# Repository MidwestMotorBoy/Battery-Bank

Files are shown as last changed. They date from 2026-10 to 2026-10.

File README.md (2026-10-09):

# Monolith battery bank

An ultralight 100 W USB-C battery bank for backpacking: four EVE INR21700-58E cells (4S1P, about 82 Wh) in a printed tube.

**Status: early draft. Nothing here has been built, test-fitted or bench-tested.**

## Contents

- `BatteryBank.kicad_*` - KiCad 10 project for the top board. The schematic is a first draft with connections made by net labels; the PCB has the outline and mechanical reference marks only.
- `Monolith.kicad_sym`, `sym-lib-table` - project symbol library.
- `docs/` - net list and early parts lists.
- `mechanical/` - STL models for the shell, cap and test-print parts, the bottom board outline (DXF), and the Python scripts that generate them.
- `tools/` - Python scripts that generate the schematic.

## Main parts

TPS25751D (USB-C PD), BQ25756 (charger and buck-boost), BQ77915 (cell protection), TPS25810 (5 V port), TPS62933 and TPS70933 (rails), STM32WB1MMC (Bluetooth).

## Known open items

Several parts are placeholders (FETs, inductors, EEPROM), no footprints are assigned, the port 1 ESD protection is not drawn, and a number of pin connections are marked for checking against the datasheets.

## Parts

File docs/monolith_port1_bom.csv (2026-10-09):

ref | part | value_or_role | package | status | JLC_part_number
U1 | TPS25751D | USB-C PD controller | WQFN-38 4x6mm | confirmed from TI datasheet
U2 | BQ25756 | Buck-boost charge controller | VQFN-36 5x6mm | confirmed from TI datasheet
Q1 | N-FET 40V <=6mOhm logic-level | Buck high side | 3.3x3.3mm | to be selected
Q2 | N-FET 40V <=6mOhm logic-level | Buck low side | 3.3x3.3mm | to be selected
Q3 | N-FET 40V <=6mOhm logic-level | Boost low side | 3.3x3.3mm | to be selected
Q4 | N-FET 40V <=6mOhm logic-level | Boost high side | 3.3x3.3mm | to be selected
L1 | Inductor | 4.7uH, Isat>=12A, <=5mm tall | about 10x10mm | to be selected
R1 | Sense resistor | 5mOhm 1% 1W | 2512 or 1206 wide | assumed, verify
R2 | Sense resistor | 5mOhm 1% 1W | 2512 or 1206 wide | confirmed from TI datasheet
C1 | Bootstrap cap | 100nF 25V | 0402 | assumed, verify
C2 | Bootstrap cap | 100nF 25V | 0402 | assumed, verify
C3 | REGN cap | 4.7uF 10V | 0603 | confirmed from TI datasheet
C4 | DRV_SUP cap | 4.7uF 10V | 0603 | confirmed from TI datasheet
C5 | VAC cap | 1uF 35V | 0603 | confirmed from TI datasheet
R3 | VAC feed | 10 Ohm | 0402 | assumed, verify
C6-C9 | Input bulk (port side) | 4x 22uF 35V X7R, plus C10 | 1210 | assumed, verify
C10 | Input bulk polymer | 68uF 25V, <=5mm tall | D case | assumed, verify
C11-C14 | Output bulk (battery side) | 4x 22uF 25V X7R, plus C15 | 1210 | assumed, verify
C15 | Battery bulk polymer | 68uF 25V, <=5mm tall | D case | assumed, verify
R4 | FB top | 243k 0.1% | 0402 | assumed, verify
R5 | FB bottom | 24.9k 0.1% | 0402 | assumed, verify
R6 | ICHG set | 16.9k 1% (2.96A) | 0402 | confirmed from TI datasheet
R7 | ILIM set | 4.02k 1% (about 5A with 5mOhm R1) | 0402 | assumed, verify
R8 | FSW set | 66.5k 1% (400kHz) | 0402 | confirmed from TI datasheet
R9 | TS upper | 5.23k 1% | 0402 | confirmed from TI datasheet
R10 | TS lower | 30.1k 1% | 0402 | confirmed from TI datasheet
RT1 | NTC on cell | 10k 103AT, on leads | wired | confirmed from TI datasheet
R11 | ACUV/ACOV divider top | value from datasheet section 6.3 | 0402 | to be selected
R12 | ACUV/ACOV divider mid | value from datasheet section 6.3 | 0402 | to be selected
R13 | ACUV/ACOV divider bottom | value from datasheet section 6.3 | 0402 | to be selected
R14 | CE pull-down | 10k | 0402 | assumed, verify
R15 | INT pull-up | 10k | 0402 | confirmed from TI datasheet
R16 | I2Cc SDA pull-up | 3.3k | 0402 | confirmed from TI datasheet
R17 | I2Cc SCL pull-up | 3.3k | 0402 | confirmed from TI datasheet
R18 | I2Ct SDA pull-up | 4.7k | 0402 | confirmed from TI datasheet
R19 | I2Ct SCL pull-up | 4.7k | 0402 | confirmed from TI datasheet
R20 | Host IRQ pull-up | 10k | 0402 | assumed, verify
R21-R23 | STAT1/STAT2/PG pull-ups | 3x 100k | 0402 | assumed, verify
C16 | LDO_3V3 cap | 10uF 6.3V | 0603 | confirmed from TI datasheet
C17 | LDO_1V5 cap | 10uF 6.3V | 0603 | confirmed from TI datasheet
C18 | VIN_3V3 cap | 10uF 6.3V | 0603 | confirmed from TI datasheet
C19 | VBUS cap | 4.7uF 35V | 0805 | confirmed from TI datasheet
C20 | PP5V cap | 22uF 10V | 0805 | confirmed from TI datasheet
C21 | CC1 cap | 330pF | 0402 | confirmed from TI datasheet
C22 | CC2 cap | 330pF | 0402 | confirmed from TI datasheet
R24,R25 | ADCIN1 strap divider | level chosen in TI GUI | 0402 | to be selected
R26,R27 | ADCIN2 strap divider | level chosen in TI GUI | 0402 | to be selected
U3 | I2C EEPROM | size and address per TPS25751 datasheet | SOT-23-5 or UDFN | to be selected
D1 | VBUS TVS | TVS2200 or equivalent | SON | confirmed from TI datasheet
D2 | CC/D+/D- ESD array | 4-channel, 24V-tolerant on CC | SOT/DFN | to be selected
J1 | Amphenol 12402082E512A | Port 1 USB-C | vertical SMT | assumed, verify
(block) | BQ77915 + 2 FETs + 5mOhm sense + 15A fuse | Protector: between cell stack and VBAT_SYS |  | pinout not yet pulled
(block) | TPS709 LDO | 3.3V rail: VBAT_SYS -> 3V3 |  | pinout not yet pulled
(block) | TPS62933 buck, J2, 4.7k CC pull-ups | 5V rail and port 2: VBAT_SYS -> 5V, 5V -> VBUS2 through a load switch |  | pinout not yet pulled
(block) | Ebyte E104-BT5005A | Bluetooth: HOST_SDA, HOST_SCL, HOST_IRQ, CHG_STAT1/2, CHG_PG, LEDs, SWD pads |  | pinout not yet pulled

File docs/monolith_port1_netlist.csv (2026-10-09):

ref | part | value_or_role | pin | pin_name | net | status
U1 | TPS25751D | USB-C PD controller | 1 | LDO_3V3 | PD_3V3 | confirmed from TI datasheet
U1 | TPS25751D | USB-C PD controller | 2 | ADCIN1 | ADCIN1 | confirmed from TI datasheet
U1 | TPS25751D | USB-C PD controller | 3 | ADCIN2 | ADCIN2 | confirmed from TI datasheet
U1 | TPS25751D | USB-C PD controller | 4 | LDO_1V5 | PD_1V5 | confirmed from TI datasheet
U1 | TPS25751D | USB-C PD controller | 5 | GPIO0 | GND | confirmed from TI datasheet
U1 | TPS25751D | USB-C PD controller | 6 | GPIO1 | GND | confirmed from TI datasheet
U1 | TPS25751D | USB-C PD controller | 7 | GPIO2 | GND | confirmed from TI datasheet
U1 | TPS25751D | USB-C PD controller | 8 | I2Ct_SDA | HOST_SDA | confirmed from TI datasheet
U1 | TPS25751D | USB-C PD controller | 9 | I2Ct_SCL | HOST_SCL | confirmed from TI datasheet
U1 | TPS25751D | USB-C PD controller | 10 | I2Ct_IRQ | HOST_IRQ | confirmed from TI datasheet
U1 | TPS25751D | USB-C PD controller | 11 | GND | GND | confirmed from TI datasheet
U1 | TPS25751D | USB-C PD controller | 12 | GND | GND | confirmed from TI datasheet
U1 | TPS25751D | USB-C PD controller | 13 | GPIO11 | GND | confirmed from TI datasheet
U1 | TPS25751D | USB-C PD controller | 14 | GND | GND | confirmed from TI datasheet
U1 | TPS25751D | USB-C PD controller | 15 | DRAIN | PD_DRAIN | confirmed from TI datasheet
U1 | TPS25751D | USB-C PD controller | 16 | I2Cc_SDA | CHG_SDA | confirmed from TI datasheet
U1 | TPS25751D | USB-C PD controller | 17 | I2Cc_SCL | CHG_SCL | confirmed from TI datasheet
U1 | TPS25751D | USB-C PD controller | 18 | I2Cc_IRQ | CHG_INT | confirmed from TI datasheet
U1 | TPS25751D | USB-C PD controller | 19 | GPIO3 | GND | confirmed from TI datasheet
U1 | TPS25751D | USB-C PD controller | 20 | PPHV | PPHV | confirmed from TI datasheet
U1 | TPS25751D | USB-C PD controller | 21 | PPHV | PPHV | confirmed from TI datasheet
U1 | TPS25751D | USB-C PD controller | 22 | PPHV | PPHV | confirmed from TI datasheet
U1 | TPS25751D | USB-C PD controller | 23 | VBUS_IN | VBUS1 | confirmed from TI datasheet
U1 | TPS25751D | USB-C PD controller | 24 | VBUS_IN | VBUS1 | confirmed from TI datasheet
U1 | TPS25751D | USB-C PD controller | 25 | VBUS_IN | VBUS1 | confirmed from TI datasheet
U1 | TPS25751D | USB-C PD controller | 26 | GPIO4/USB_P | P1_DP | confirmed from TI datasheet
U1 | TPS25751D | USB-C PD controller | 27 | GPIO5/USB_N | P1_DN | confirmed from TI datasheet
U1 | TPS25751D | USB-C PD controller | 28 | CC1 | P1_CC1 | confirmed from TI datasheet
U1 | TPS25751D | USB-C PD controller | 29 | CC2 | P1_CC2 | confirmed from TI datasheet
U1 | TPS25751D | USB-C PD controller | 30 | DRAIN | PD_DRAIN | confirmed from TI datasheet
U1 | TPS25751D | USB-C PD controller | 31 | GND | GND | confirmed from TI datasheet
U1 | TPS25751D | USB-C PD controller | 32 | VBUS | VBUS1 | confirmed from TI datasheet
U1 | TPS25751D | USB-C PD controller | 33 | VBUS | VBUS1 | confirmed from TI datasheet
U1 | TPS25751D | USB-C PD controller | 34 | PP5V | 5V | confirmed from TI datasheet
U1 | TPS25751D | USB-C PD controller | 35 | PP5V | 5V | confirmed from TI datasheet
U1 | TPS25751D | USB-C PD controller | 36 | GPIO7 | GND | confirmed from TI datasheet
U1 | TPS25751D | USB-C PD controller | 37 | GPIO6 | GND | confirmed from TI datasheet
U1 | TPS25751D | USB-C PD controller | 38 | VIN_3V3 | 3V3 | confirmed from TI datasheet
U1 | TPS25751D | USB-C PD controller | EP1 | GND pad | GND | confirmed from TI datasheet
U1 | TPS25751D | USB-C PD controller | EP2 | DRAIN pad | PD_DRAIN | confirmed from TI datasheet
U2 | BQ25756 | Buck-boost charge controller | 1 | SCL | CHG_SCL | confirmed from TI datasheet
U2 | BQ25756 | Buck-boost charge controller | 2 | SDA | CHG_SDA | confirmed from TI datasheet
U2 | BQ25756 | Buck-boost charge controller | 3 | INT | CHG_INT | confirmed from TI datasheet
U2 | BQ25756 | Buck-boost charge controller | 4 | STAT1 | CHG_STAT1 | confirmed from TI datasheet
U2 | BQ25756 | Buck-boost charge controller | 5 | STAT2 | CHG_STAT2 | confirmed from TI datasheet
U2 | BQ25756 | Buck-boost charge controller | 6 | PG | CHG_PG | confirmed from TI datasheet
U2 | BQ25756 | Buck-boost charge controller | 7 | CE | CHG_CE_N | confirmed from TI datasheet
U2 | BQ25756 | Buck-boost charge controller | 8 | TS | CHG_TS | confirmed from TI datasheet
U2 | BQ25756 | Buck-boost charge controller | 9 | ICHG | CHG_ICHG | confirmed from TI datasheet
U2 | BQ25756 | Buck-boost charge controller | 10 | ILIM_HIZ | CHG_ILIM | confirmed from TI datasheet
U2 | BQ25756 | Buck-boost charge controller | 11 | FBG | CHG_FBG | confirmed from TI datasheet
U2 | BQ25756 | Buck-boost charge controller | 12 | FB | CHG_FB | confirmed from TI datasheet
U2 | BQ25756 | Buck-boost charge controller | 13 | SRN | VBAT_SYS | confirmed from TI datasheet
U2 | BQ25756 | Buck-boost charge controller | 14 | SRP | BAT_SNS_P | confirmed from TI datasheet
U2 | BQ25756 | Buck-boost charge controller | 15 | NC | no connect | confirmed from TI datasheet
U2 | BQ25756 | Buck-boost charge controller | 16 | NC | no connect | confirmed from TI datasheet
U2 | BQ25756 | Buck-boost charge controller | 17 | PGND | GND | confirmed from TI datasheet
U2 | BQ25756 | Buck-boost charge controller | 18 | SW2 | SW2 | confirmed from TI datasheet
U2 | BQ25756 | Buck-boost charge controller | 19 | HIDRV2 | HG2 | confirmed from TI datasheet
U2 | BQ25756 | Buck-boost charge controller | 20 | BTST2 | BTST2 | confirmed from TI datasheet
U2 | BQ25756 | Buck-boost charge controller | 21 | LODRV2 | LG2 | confirmed from TI datasheet
U2 | BQ25756 | Buck-boost charge controller | 22 | PGND | GND | confirmed from TI datasheet
U2 | BQ25756 | Buck-boost charge controller | 23 | DRV_SUP | REGN | confirmed from TI datasheet
U2 | BQ25756 | Buck-boost charge controller | 24 | REGN | REGN | confirmed from TI datasheet
U2 | BQ25756 | Buck-boost charge controller | 25 | LODRV1 | LG1 | confirmed from TI datasheet
U2 | BQ25756 | Buck-boost charge controller | 26 | BTST1 | BTST1 | confirmed from TI datasheet
U2 | BQ25756 | Buck-boost charge controller | 27 | HIDRV1 | HG1 | confirmed from TI datasheet
U2 | BQ25756 | Buck-boost charge controller | 28 | SW1 | SW1 | confirmed from TI datasheet
U2 | BQ25756 | Buck-boost charge controller | 29 | ACN | AC_SNS_N | confirmed from TI datasheet
U2 | BQ25756 | Buck-boost charge controller | 30 | ACP | PPHV | confirmed from TI datasheet
U2 | BQ25756 | Buck-boost charge controller | 31 | NC | no connect | confirmed from TI datasheet
U2 | BQ25756 | Buck-boost charge controller | 32 | VAC | CHG_VAC | confirmed from TI datasheet
U2 | BQ25756 | Buck-boost charge controller | 33 | VAC | CHG_VAC | confirmed from TI datasheet
U2 | BQ25756 | Buck-boost charge controller | 34 | ACUV | CHG_ACUV | confirmed from TI datasheet
U2 | BQ25756 | Buck-boost charge controller | 35 | ACOV | CHG_ACOV | confirmed from TI datasheet
U2 | BQ25756 | Buck-boost charge controller | 36 | FSW_SYNC | CHG_FSW | confirmed from TI datasheet
U2 | BQ25756 | Buck-boost charge controller | EP | Thermal pad | GND | confirmed from TI datasheet
Q1 | N-FET 40V <=6mOhm logic-level | Buck high side | D | drain | AC_SNS_N | to be selected
Q1 | N-FET 40V <=6mOhm logic-level | Buck high side | G | gate | HG1 | to be selected
Q1 | N-FET 40V <=6mOhm logic-level | Buck high side | S | source | SW1 | to be selected
Q2 | N-FET 40V <=6mOhm logic-level | Buck low side | D | drain | SW1 | to be selected
Q2 | N-FET 40V <=6mOhm logic-level | Buck low side | G | gate | LG1 | to be selected
Q2 | N-FET 40V <=6mOhm logic-level | Buck low side | S | source | GND | to be selected
Q3 | N-FET 40V <=6mOhm logic-level | Boost low side | D | drain | SW2 | to be selected
Q3 | N-FET 40V <=6mOhm logic-level | Boost low side | G | gate | LG2 | to be selected
Q3 | N-FET 40V <=6mOhm logic-level | Boost low side | S | source | GND | to be selected
Q4 | N-FET 40V <=6mOhm logic-level | Boost high side | D | drain | BAT_SNS_P | to be selected
Q4 | N-FET 40V <=6mOhm logic-level | Boost high side | G | gate | HG2 | to be selected
Q4 | N-FET 40V <=6mOhm logic-level | Boost high side | S | source | SW2 | to be selected
L1 | Inductor | 4.7uH, Isat>=12A, <=5mm tall | 1 |  | SW1 | to be selected
L1 | Inductor | 4.7uH, Isat>=12A, <=5mm tall | 2 |  | SW2 | to be selected
R1 | Sense resistor | 5mOhm 1% 1W | 1 |  | PPHV | assumed, verify
R1 | Sense resistor | 5mOhm 1% 1W | 2 |  | AC_SNS_N | assumed, verify
R2 | Sense resistor | 5mOhm 1% 1W | 1 |  | BAT_SNS_P | confirmed from TI datasheet
R2 | Sense resistor | 5mOhm 1% 1W | 2 |  | VBAT_SYS | confirmed from TI datasheet
C1 | Bootstrap cap | 100nF 25V | 1 |  | BTST1 | assumed, verify
C1 | Bootstrap cap | 100nF 25V | 2 |  | SW1 | assumed, verify
C2 | Bootstrap cap | 100nF 25V | 1 |  | BTST2 | assumed, verify
C2 | Bootstrap cap | 100nF 25V | 2 |  | SW2 | assumed, verify
C3 | REGN cap | 4.7uF 10V | 1 |  | REGN | confirmed from TI datasheet
C3 | REGN cap | 4.7uF 10V | 2 |  | GND | confirmed from TI datasheet
C4 | DRV_SUP cap | 4.7uF 10V | 1 |  | REGN | confirmed from TI datasheet
C4 | DRV_SUP cap | 4.7uF 10V | 2 |  | GND | confirmed from TI datasheet
C5 | VAC cap | 1uF 35V | 1 |  | CHG_VAC | confirmed from TI datasheet
C5 | VAC cap | 1uF 35V | 2 |  | GND | confirmed from TI datasheet
R3 | VAC feed | 10 Ohm | 1 |  | PPHV | assumed, verify
R3 | VAC feed | 10 Ohm | 2 |  | CHG_VAC | assumed, verify
C6-C9 | Input bulk (port side) | 4x 22uF 35V X7R, plus C10 | 1 |  | AC_SNS_N | assumed, verify
C6-C9 | Input bulk (port side) | 4x 22uF 35V X7R, plus C10 | 2 |  | GND | assumed, verify
C10 | Input bulk polymer | 68uF 25V, <=5mm tall | 1 |  | PPHV | assumed, verify
C10 | Input bulk polymer | 68uF 25V, <=5mm tall | 2 |  | GND | assumed, verify
C11-C14 | Output bulk (battery side) | 4x 22uF 25V X7R, plus C15 | 1 |  | BAT_SNS_P | assumed, verify
C11-C14 | Output bulk (battery side) | 4x 22uF 25V X7R, plus C15 | 2 |  | GND | assumed, verify
C15 | Battery bulk polymer | 68uF 25V, <=5mm tall | 1 |  | VBAT_SYS | assumed, verify
C15 | Battery bulk polymer | 68uF 25V, <=5mm tall | 2 |  | GND | assumed, verify
R4 | FB top | 243k 0.1% | 1 |  | VBAT_SYS | assumed, verify
R4 | FB top | 243k 0.1% | 2 |  | CHG_FB | assumed, verify
R5 | FB bottom | 24.9k 0.1% | 1 |  | CHG_FB | assumed, verify
R5 | FB bottom | 24.9k 0.1% | 2 |  | CHG_FBG | assumed, verify
R6 | ICHG set | 16.9k 1% (2.96A) | 1 |  | CHG_ICHG | confirmed from TI datasheet
R6 | ICHG set | 16.9k 1% (2.96A) | 2 |  | GND | confirmed from TI datasheet
R7 | ILIM set | 4.02k 1% (about 5A with 5mOhm R1) | 1 |  | CHG_ILIM | assumed, verify
R7 | ILIM set | 4.02k 1% (about 5A with 5mOhm R1) | 2 |  | GND | assumed, verify
R8 | FSW set | 66.5k 1% (400kHz) | 1 |  | CHG_FSW | confirmed from TI datasheet
R8 | FSW set | 66.5k 1% (400kHz) | 2 |  | GND | confirmed from TI datasheet
R9 | TS upper | 5.23k 1% | 1 |  | REGN | confirmed from TI datasheet
R9 | TS upper | 5.23k 1% | 2 |  | CHG_TS | confirmed from TI datasheet
R10 | TS lower | 30.1k 1% | 1 |  | CHG_TS | confirmed from TI datasheet
R10 | TS lower | 30.1k 1% | 2 |  | GND | confirmed from TI datasheet
RT1 | NTC on cell | 10k 103AT, on leads | 1 |  | CHG_TS | confirmed from TI datasheet
RT1 | NTC on cell | 10k 103AT, on leads | 2 |  | GND | confirmed from TI datasheet
R11 | ACUV/ACOV divider top | value from datasheet section 6.3 | 1 |  | CHG_VAC | to be selected
R11 | ACUV/ACOV divider top | value from datasheet section 6.3 | 2 |  | CHG_ACOV | to be selected
R12 | ACUV/ACOV divider mid | value from datasheet section 6.3 | 1 |  | CHG_ACOV | to be selected
R12 | ACUV/ACOV divider mid | value from datasheet section 6.3 | 2 |  | CHG_ACUV | to be selected
R13 | ACUV/ACOV divider bottom | value from datasheet section 6.3 | 1 |  | CHG_ACUV | to be selected
R13 | ACUV/ACOV divider bottom | value from datasheet section 6.3 | 2 |  | GND | to be selected
R14 | CE pull-down | 10k | 1 |  | CHG_CE_N | assumed, verify
R14 | CE pull-down | 10k | 2 |  | GND | assumed, verify
R15 | INT pull-up | 10k | 1 |  | CHG_INT | confirmed from TI datasheet
R15 | INT pull-up | 10k | 2 |  | PD_3V3 | confirmed from TI datasheet
R16 | I2Cc SDA pull-up | 3.3k | 1 |  | CHG_SDA | confirmed from TI datasheet
R16 | I2Cc SDA pull-up | 3.3k | 2 |  | PD_3V3 | confirmed from TI datasheet
R17 | I2Cc SCL pull-up | 3.3k | 1 |  | CHG_SCL | confirmed from TI datasheet
R17 | I2Cc SCL pull-up | 3.3k | 2 |  | PD_3V3 | confirmed from TI datasheet
R18 | I2Ct SDA pull-up | 4.7k | 1 |  | HOST_SDA | confirmed from TI datasheet
R18 | I2Ct SDA pull-up | 4.7k | 2 |  | 3V3 | confirmed from TI datasheet
R19 | I2Ct SCL pull-up | 4.7k | 1 |  | HOST_SCL | confirmed from TI datasheet
R19 | I2Ct SCL pull-up | 4.7k | 2 |  | 3V3 | confirmed from TI datasheet
R20 | Host IRQ pull-up | 10k | 1 |  | HOST_IRQ | assumed, verify
R20 | Host IRQ pull-up | 10k | 2 |  | 3V3 | assumed, verify
R21-R23 | STAT1/STAT2/PG pull-ups | 3x 100k | 1 |  | CHG_STAT1 / CHG_STAT2 / CHG_PG | assumed, verify
R21-R23 | STAT1/STAT2/PG pull-ups | 3x 100k | 2 |  | 3V3 | assumed, verify
C16 | LDO_3V3 cap | 10uF 6.3V | 1 |  | PD_3V3 | confirmed from TI datasheet
C16 | LDO_3V3 cap | 10uF 6.3V | 2 |  | GND | confirmed from TI datasheet
C17 | LDO_1V5 cap | 10uF 6.3V | 1 |  | PD_1V5 | confirmed from TI datasheet
C17 | LDO_1V5 cap | 10uF 6.3V | 2 |  | GND | confirmed from TI datasheet
C18 | VIN_3V3 cap | 10uF 6.3V | 1 |  | 3V3 | confirmed from TI datasheet
C18 | VIN_3V3 cap | 10uF 6.3V | 2 |  | GND | confirmed from TI datasheet
C19 | VBUS cap | 4.7uF 35V | 1 |  | VBUS1 | confirmed from TI datasheet
C19 | VBUS cap | 4.7uF 35V | 2 |  | GND | confirmed from TI datasheet
C20 | PP5V cap | 22uF 10V | 1 |  | 5V | confirmed from TI datasheet
C20 | PP5V cap | 22uF 10V | 2 |  | GND | confirmed from TI datasheet
C21 | CC1 cap | 330pF | 1 |  | P1_CC1 | confirmed from TI datasheet
C21 | CC1 cap | 330pF | 2 |  | GND | confirmed from TI datasheet
C22 | CC2 cap | 330pF | 1 |  | P1_CC2 | confirmed from TI datasheet
C22 | CC2 cap | 330pF | 2 |  | GND | confirmed from TI datasheet
R24,R25 | ADCIN1 strap divider | level chosen in TI GUI | 1 |  | PD_3V3 / GND | to be selected
R24,R25 | ADCIN1 strap divider | level chosen in TI GUI | 2 |  | ADCIN1 | to be selected
R26,R27 | ADCIN2 strap divider | level chosen in TI GUI | 1 |  | PD_3V3 / GND | to be selected
R26,R27 | ADCIN2 strap divider | level chosen in TI GUI | 2 |  | ADCIN2 | to be selected
U3 | I2C EEPROM | size and address per TPS25751 datasheet | SDA |  | CHG_SDA | to be selected
U3 | I2C EEPROM | size and address per TPS25751 datasheet | SCL |  | CHG_SCL | to be selected
U3 | I2C EEPROM | size and address per TPS25751 datasheet | VCC |  | PD_3V3 | to be selected
U3 | I2C EEPROM | size and address per TPS25751 datasheet | GND |  | GND | to be selected
D1 | VBUS TVS | TVS2200 or equivalent | 1 |  | VBUS1 | confirmed from TI datasheet
D1 | VBUS TVS | TVS2200 or equivalent | 2 |  | GND | confirmed from TI datasheet
D2 | CC/D+/D- ESD array | 4-channel, 24V-tolerant on CC | IO |  | P1_CC1, P1_CC2, P1_DP, P1_DN | to be selected
D2 | CC/D+/D- ESD array | 4-channel, 24V-tolerant on CC | GND |  | GND | to be selected
J1 | Amphenol 12402082E512A | Port 1 USB-C | VBUS | A4/A9/B4/B9 | VBUS1 | assumed, verify
J1 | Amphenol 12402082E512A | Port 1 USB-C | GND | A1/A12/B1/B12/shell | GND | assumed, verify
J1 | Amphenol 12402082E512A | Port 1 USB-C | CC1 | A5 | P1_CC1 | assumed, verify
J1 | Amphenol 12402082E512A | Port 1 USB-C | CC2 | B5 | P1_CC2 | assumed, verify
J1 | Amphenol 12402082E512A | Port 1 USB-C | D+ | A6/B6 | P1_DP | assumed, verify
J1 | Amphenol 12402082E512A | Port 1 USB-C | D- | A7/B7 | P1_DN | assumed, verify

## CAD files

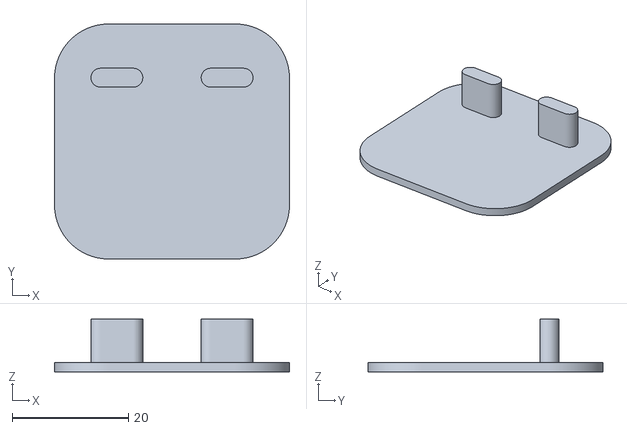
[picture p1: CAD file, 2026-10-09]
mechanical/monolith_top_board_dummy.stl
40.5 x 40.5 x 9.10

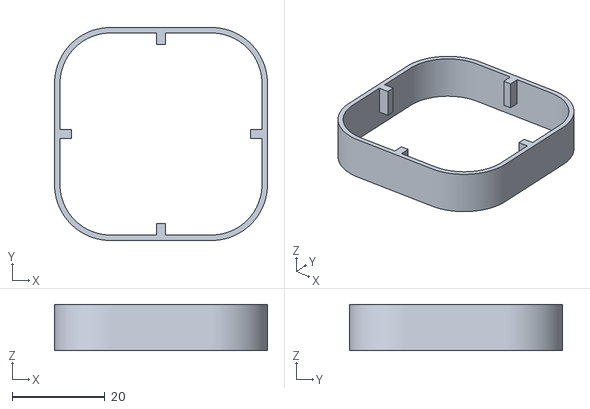
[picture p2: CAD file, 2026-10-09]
mechanical/monolith_fit_ring.stl
46.0 x 46.0 x 10.0

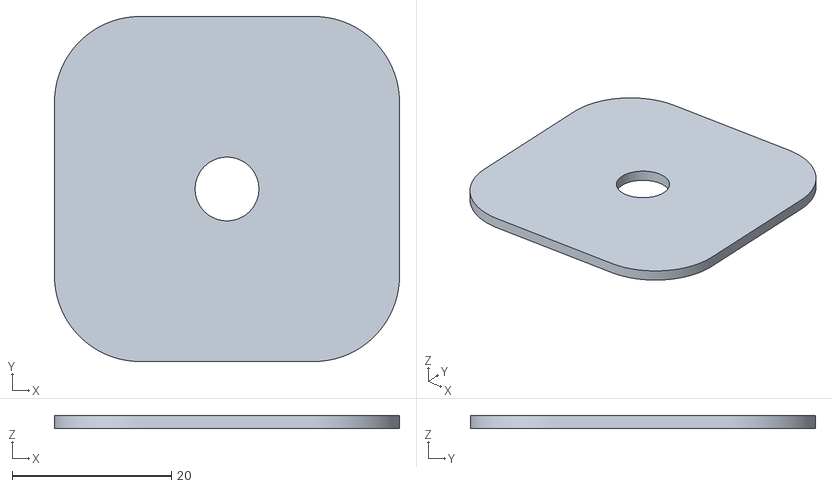
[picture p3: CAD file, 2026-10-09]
mechanical/monolith_bottom_pcb_dummy.stl
43.3 x 43.3 x 1.60

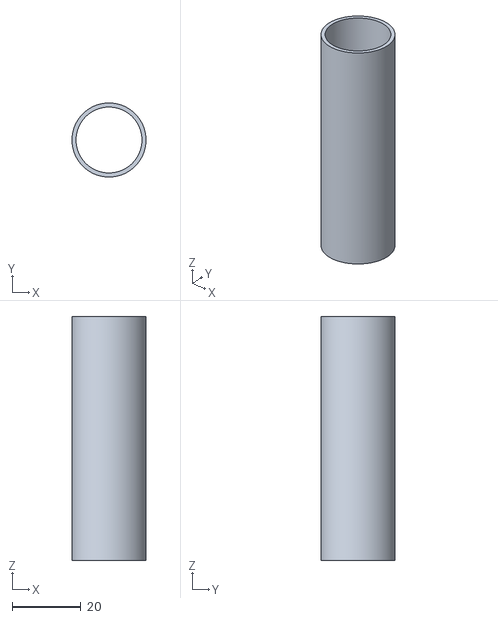
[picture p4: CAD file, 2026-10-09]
mechanical/monolith_cell_dummy.stl
21.5 x 21.5 x 70.8

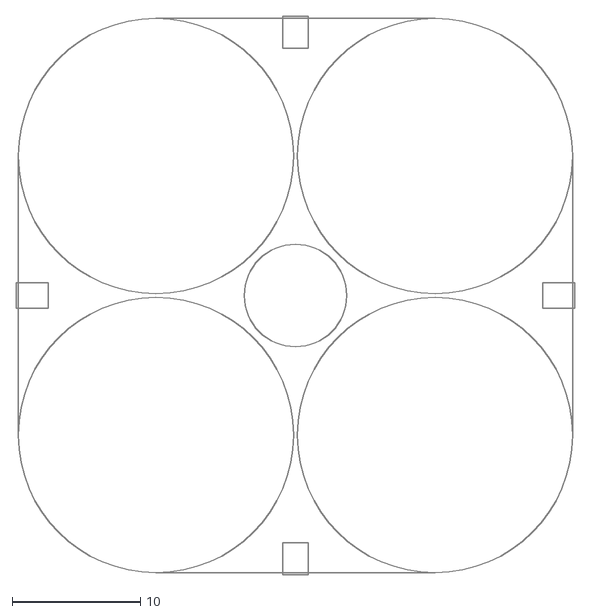
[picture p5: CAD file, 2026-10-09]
mechanical/monolith_bottom_pcb.dxf
43.6 x 43.6

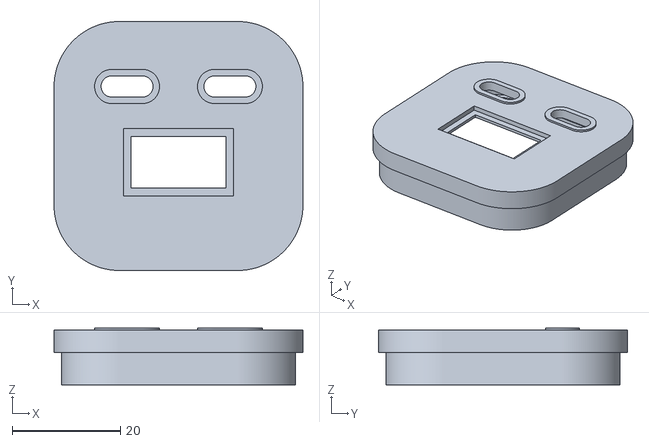
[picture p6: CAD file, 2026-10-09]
mechanical/monolith_top_cap.stl
46.0 x 46.0 x 10.5

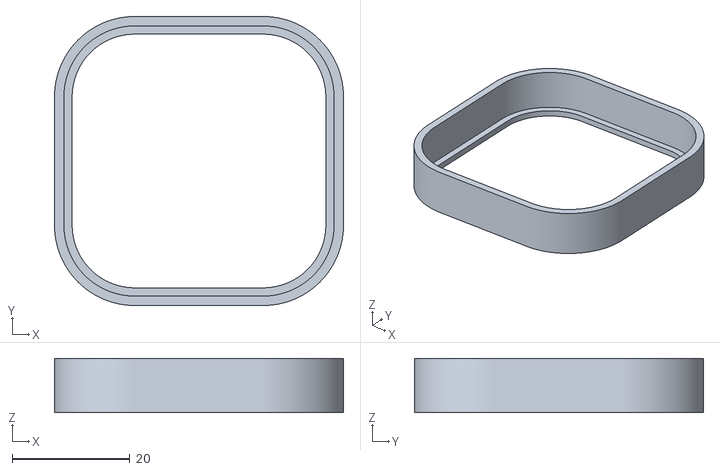
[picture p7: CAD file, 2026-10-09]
mechanical/monolith_end_bumper.stl
49.0 x 49.0 x 9.20

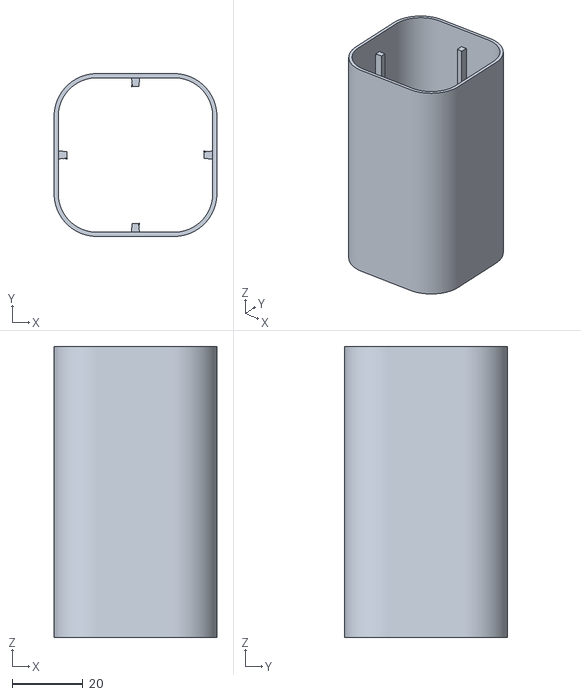
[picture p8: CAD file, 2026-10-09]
mechanical/monolith_shell.stl
46.0 x 46.0 x 82.2

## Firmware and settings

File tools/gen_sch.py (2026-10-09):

import uuid, io, contextlib
with contextlib.redirect_stdout(io.StringIO()):
    import gen
ROOT = "87221f23-e3e9-4980-bed8-cd30d4c8eaab"
U = lambda: str(uuid.uuid4())
F = '(effects (font (size 1.27 1.27))'
def q(s): return '"' + str(s).replace('"', "'") + '"'
G = 2.54
# ---------- library symbols ----------
def prop_lib(ref, val):
    return (f'(property "Reference" {q(ref)} (at 0 0 0) {F}))\n(property "Value" {q(val)} (at 0 0 0) {F}))\n'
            f'(property "Footprint" "" (at 0 0 0) {F} (hide yes)))\n(property "Datasheet" "" (at 0 0 0) {F} (hide yes)))\n'
            f'(property "Description" "" (at 0 0 0) {F} (hide yes)))')
def pin(num, name, x, y, ang, ln=2.54):
    return f'(pin passive line (at {x:.2f} {y:.2f} {ang}) (length {ln}) (name {q(name)} {F})) (number {q(num)} {F})))'
def libsym(name, ref, pins, rect, hide=False, extra=""):
    h = "(pin_numbers hide) (pin_names (offset 0) hide)" if hide else "(pin_names (offset 1.016))"
    x0, y0, x1, y1 = rect
    return (f'(symbol "Monolith:{name}" {h} (exclude_from_sim no) (in_bom yes) (on_board yes)\n{prop_lib(ref, name)}\n'
            f'(symbol "{name}_0_1" (rectangle (start {x0} {y0}) (end {x1} {y1}) (stroke (width 0.254) (type default)) (fill (type background))){extra})\n'
            f'(symbol "{name}_1_1"\n' + "\n".join(pins) + "))")
LIB = {}; PINPOS = {}       # PINPOS[sym][num] = (dx, dy_lib, side)
def ic(name, pins):
    n = len(pins); nl = (n + 1) // 2; W = 15.24; top = (nl - 1) * G / 2; H = top + G
    out = []; pos = {}
    for i, (num, nm) in enumerate(pins):
        if i < nl: x, y, a, side = -W - G, top - i * G, 0, "L"
        else: j = n - 1 - i; x, y, a, side = W + G, top - j * G, 180, "R"
        out.append(pin(num, nm, x, y, a)); pos[str(num)] = (x, y, side)
    LIB[name] = libsym(name, "U", out, (-W, H, W, -H)); PINPOS[name] = pos
def two(name, ref):
    LIB[name] = libsym(name, ref, [pin("1", "~", 0, 3.81, 270, 1.27), pin("2", "~", 0, -3.81, 90, 1.27)], (-1.016, 2.54, 1.016, -2.54), hide=True)
    PINPOS[name] = {"1": (0, 3.81, "R"), "2": (0, -3.81, "R")}
ic("TPS25751D", [(p, n) for p, n, _ in gen.parts[0][5]])
ic("BQ25756", [(p, n) for p, n, _ in gen.parts[1][5]])
for n, r in (("R", "R"), ("C", "C"), ("L", "L"), ("TVS", "D"), ("NTC", "RT")): two(n, r)
LIB["NFET"] = libsym("NFET", "Q", [pin(n, "S", 0, -5.08, 90) for n in "123"] + [pin("4", "G", -5.08, 0, 0)] + [pin(n, "D", 0, 5.08, 270) for n in "5678"], (-2.54, 2.54, 2.54, -2.54))
PINPOS["NFET"] = {**{n: (0, -5.08, "R") for n in "123"}, "4": (-5.08, 0, "L"), **{n: (0, 5.08, "R") for n in "5678"}}
LIB["ESD_DUAL"] = libsym("ESD_DUAL", "D", [pin("1", "K1", -5.08, 2.54, 0), pin("2", "K2", -5.08, -2.54, 0), pin("3", "A", 5.08, 0, 180)], (-2.54, 5.08, 2.54, -5.08))
PINPOS["ESD_DUAL"] = {"1": (-5.08, 2.54, "L"), "2": (-5.08, -2.54, "L"), "3": (5.08, 0, "R")}
two("FUSE", "F"); two("LED", "D")
GNDP = [1, 2, 3, 4, 5, 8, 15, 17, 19, 21, 24, 31] + list(range(43, 78))
WBN = {6: "ANT_IN", 7: "ANT_OUT", 9: "PA4", 10: "PA8", 11: "PA1", 12: "PA6", 13: "PA2", 14: "PB8", 16: "VDDA", 18: "VBAT", 20: "VDDSMPS", 22: "BOOT0", 23: "NRST",
       25: "PB7", 26: "PB5", 27: "PB6", 28: "PA3", 29: "PA7", 30: "PA12", 32: "PA11", 33: "PB4", 34: "PA14", 35: "PA13", 36: "PA10", 37: "PA0", 38: "PA9", 39: "PA5",
       40: "PB1", 41: "PB0", 42: "PB2"}
ic("STM32WB1MMC", [(k, WBN[k]) for k in sorted(WBN)] + [(k, "VSSRF" if k in (5, 8) else "VSSSMPS" if k == 21 else "VSS") for k in GNDP])
ic("TPS25810", [(1, "FAULT"), (2, "IN1"), (3, "IN1"), (4, "IN2"), (5, "AUX"), (6, "EN"), (7, "CHG"), (8, "CHG_HI"), (9, "REF_RTN"), (10, "REF"), (11, "CC1"), (12, "GND"),
                (13, "CC2"), (14, "OUT"), (15, "OUT"), (16, "DEBUG"), (17, "AUDIO"), (18, "POL"), (19, "UFP"), (20, "LD_DET"), ("EP", "Thermal pad")])
LIB["PAD"] = libsym("PAD", "W", [pin("1", "~", 2.54, 0, 180, 2.54)], (-1.27, 1.27, 0, -1.27), hide=True)
PINPOS["PAD"] = {"1": (2.54, 0, "R")}
ic("BQ77915", [(i + 1, n) for i, n in enumerate("VDD AVDD VC5 VC4 VC3 VC2 VC1 VC0 VSS SRP SRN DSG CHG LD LPWR CBI OCDP TS VTB CCFG CBO PRES CTRC CTRD".split())])
ic("TPS70933DBV", [(1, "IN"), (2, "GND"), (3, "EN"), (4, "NC"), (5, "OUT")])
ic("TPS62933DRL", [(1, "RT"), (2, "EN"), (3, "VIN"), (4, "GND"), (5, "SW"), (6, "BST"), (7, "SS"), (8, "FB")])
ic("USB_C_Port", [("VBUS", "VBUS"), ("CC1", "CC1"), ("CC2", "CC2"), ("D+", "D+"), ("D-", "D-"), ("GND", "GND")])
ic("EEPROM_24C512", [("1", "A0"), ("2", "A1"), ("3", "A2"), ("4", "VSS"), ("5", "SDA"), ("6", "SCL"), ("7", "WP"), ("8", "VCC")])
# ---------- placement ----------
body = []; netcheck = {}
def footprint(sym, ref, val):
    R, C = "Resistor_SMD:", "Capacitor_SMD:"
    if sym == "R": return R + ("R_2512_6332Metric" if val.startswith(("5m", "3m")) else "R_0402_1005Metric")
    if sym == "C":
        if "poly" in val: return ""
        if val.startswith("22u 25V") or val.startswith("22u 35V"): return C + "C_1210_3225Metric"
        if val.startswith("10u 35V"): return C + "C_1206_3216Metric"
        if val.startswith(("22u", "4.7u 35V")): return C + "C_0805_2012Metric"
        if val.startswith(("10u", "4.7u", "2.2u", "1u")): return C + "C_0603_1608Metric"
        return C + "C_0402_1005Metric"
    if sym == "LED": return "LED_SMD:LED_0603_1608Metric"
    if sym == "ESD_DUAL": return "Package_TO_SOT_SMD:SOT-23"
    if sym == "PAD": return "TestPoint:TestPoint_Pad_4.0x4.0mm" if "wire" in val else "TestPoint:TestPoint_Pad_D1.5mm"
    return {"U3": "Package_SO:TSSOP-8_4.4x3mm_P0.65mm", "U4": "Package_SO:TSSOP-24_4.4x7.8mm_P0.65mm", "U5": "Package_TO_SOT_SMD:SOT-23-5",
            "U6": "Package_TO_SOT_SMD:SOT-583-8"}.get(ref, "")
FPCOUNT = [0, 0]; NOFP = []
LCSC = {**{f"Q{i}": "C41349455" for i in range(1, 7)}, "U2": "C19272232", "U8": "C473913", "U5": "C89347", "L2": "C408446", "D3": "C477999", "U3": "C169114"}
TI = "https://www.ti.com/lit/ds/symlink/"
DS = {"U1": TI + "tps25751.pdf", "U2": TI + "bq25756.pdf", "U4": TI + "bq77915.pdf", "U5": TI + "tps709.pdf", "U6": TI + "tps62933.pdf",
      "D1": TI + "tvs2200.pdf", "U8": TI + "tps25810.pdf", "U7": "https://www.st.com/resource/en/datasheet/stm32wb1mmc.pdf", "J2": "https://cdn.amphenol-cs.com/media/wysiwyg/files/drawing/c12402082.pdf", "J1": "https://cdn.amphenol-cs.com/media/wysiwyg/files/drawing/c12402082.pdf"}
def place(sym, ref, val, x, y, nets, status=""):
    pins = PINPOS[sym]; isic = len(pins) > 3 and sym not in ("NFET", "ESD_DUAL")
    if sym == "NFET": nets = {**{n: nets["S"] for n in "123"}, "4": nets["G"], **{n: nets["D"] for n in "5678"}}
    seen = set(); fp = footprint(sym, ref, val); FPCOUNT[0 if fp else 1] += 1
    if not fp: NOFP.append(ref)
    top = max(p[1] for p in pins.values())
    rx, ry = (x, y - (top + 6.35)) if isic else (x - 2.54, y - 1.27)
    vx, vy = (x, y - (top + 3.81)) if isic else (x - 2.54, y + 1.27)
    j = "" if isic else " (justify right)"
    if sym in ("NFET", "ESD_DUAL"): rx, ry, vx, vy, j = x + 3.81, y - 1.27, x + 3.81, y + 1.27, " (justify left)"
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

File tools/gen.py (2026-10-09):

import csv
# (ref, part, value, package, status, [(pin, pin_name, net), ...])
C = "confirmed from TI datasheet"; A = "assumed, verify"; T = "to be selected"
parts = [
("U1","TPS25751D","USB-C PD controller","WQFN-38 4x6mm",C,[
 (1,"LDO_3V3","PD_3V3"),(2,"ADCIN1","ADCIN1"),(3,"ADCIN2","ADCIN2"),(4,"LDO_1V5","PD_1V5"),
 (5,"GPIO0","GND"),(6,"GPIO1","GND"),(7,"GPIO2","GND"),(8,"I2Ct_SDA","HOST_SDA"),(9,"I2Ct_SCL","HOST_SCL"),(10,"I2Ct_IRQ","HOST_IRQ"),
 (11,"GND","GND"),(12,"GND","GND"),(13,"GPIO11","GND"),(14,"GND","GND"),(15,"DRAIN","PD_DRAIN"),
 (16,"I2Cc_SDA","CHG_SDA"),(17,"I2Cc_SCL","CHG_SCL"),(18,"I2Cc_IRQ","CHG_INT"),(19,"GPIO3","GND"),
 (20,"PPHV","PPHV"),(21,"PPHV","PPHV"),(22,"PPHV","PPHV"),(23,"VBUS_IN","VBUS1"),(24,"VBUS_IN","VBUS1"),(25,"VBUS_IN","VBUS1"),
 (26,"GPIO4/USB_P","P1_DP"),(27,"GPIO5/USB_N","P1_DN"),(28,"CC1","P1_CC1"),(29,"CC2","P1_CC2"),(30,"DRAIN","PD_DRAIN"),(31,"GND","GND"),
 (32,"VBUS","VBUS1"),(33,"VBUS","VBUS1"),(34,"PP5V","5V"),(35,"PP5V","5V"),(36,"GPIO7","GND"),(37,"GPIO6","GND"),(38,"VIN_3V3","3V3"),
 ("EP1","GND pad","GND"),("EP2","DRAIN pad","PD_DRAIN")]),
("U2","BQ25756","Buck-boost charge controller","VQFN-36 5x6mm",C,[
 (1,"SCL","CHG_SCL"),(2,"SDA","CHG_SDA"),(3,"INT","CHG_INT"),(4,"STAT1","CHG_STAT1"),(5,"STAT2","CHG_STAT2"),(6,"PG","CHG_PG"),
 (7,"CE","CHG_CE_N"),(8,"TS","CHG_TS"),(9,"ICHG","CHG_ICHG"),(10,"ILIM_HIZ","CHG_ILIM"),(11,"FBG","CHG_FBG"),(12,"FB","CHG_FB"),
 (13,"SRN","VBAT_SYS"),(14,"SRP","BAT_SNS_P"),(15,"NC",""),(16,"NC",""),(17,"PGND","GND"),(18,"SW2","SW2"),(19,"HIDRV2","HG2"),
 (20,"BTST2","BTST2"),(21,"LODRV2","LG2"),(22,"PGND","GND"),(23,"DRV_SUP","REGN"),(24,"REGN","REGN"),(25,"LODRV1","LG1"),
 (26,"BTST1","BTST1"),(27,"HIDRV1","HG1"),(28,"SW1","SW1"),(29,"ACN","AC_SNS_N"),(30,"ACP","PPHV"),(31,"NC",""),
 (32,"VAC","CHG_VAC"),(33,"VAC","CHG_VAC"),(34,"ACUV","CHG_ACUV"),(35,"ACOV","CHG_ACOV"),(36,"FSW_SYNC","CHG_FSW"),("EP","Thermal pad","GND")]),
("Q1","N-FET 40V <=6mOhm logic-level","Buck high side","3.3x3.3mm",T,[("D","drain","AC_SNS_N"),("G","gate","HG1"),("S","source","SW1")]),
("Q2","N-FET 40V <=6mOhm logic-level","Buck low side","3.3x3.3mm",T,[("D","drain","SW1"),("G","gate","LG1"),("S","source","GND")]),
("Q3","N-FET 40V <=6mOhm logic-level","Boost low side","3.3x3.3mm",T,[("D","drain","SW2"),("G","gate","LG2"),("S","source","GND")]),
("Q4","N-FET 40V <=6mOhm logic-level","Boost high side","3.3x3.3mm",T,[("D","drain","BAT_SNS_P"),("G","gate","HG2"),("S","source","SW2")]),
("L1","Inductor","4.7uH, Isat>=12A, <=5mm tall","about 10x10mm",T,[(1,"","SW1"),(2,"","SW2")]),
("R1","Sense resistor","5mOhm 1% 1W","2512 or 1206 wide",A,[(1,"","PPHV"),(2,"","AC_SNS_N")]),
("R2","Sense resistor","5mOhm 1% 1W","2512 or 1206 wide",C,[(1,"","BAT_SNS_P"),(2,"","VBAT_SYS")]),
("C1","Bootstrap cap","100nF 25V","0402",A,[(1,"","BTST1"),(2,"","SW1")]),
("C2","Bootstrap cap","100nF 25V","0402",A,[(1,"","BTST2"),(2,"","SW2")]),
("C3","REGN cap","4.7uF 10V","0603",C,[(1,"","REGN"),(2,"","GND")]),
("C4","DRV_SUP cap","4.7uF 10V","0603",C,[(1,"","REGN"),(2,"","GND")]),
("C5","VAC cap","1uF 35V","0603",C,[(1,"","CHG_VAC"),(2,"","GND")]),
("R3","VAC feed","10 Ohm","0402",A,[(1,"","PPHV"),(2,"","CHG_VAC")]),
("C6-C9","Input bulk (port side)","4x 22uF 35V X7R, plus C10","1210",A,[(1,"","AC_SNS_N"),(2,"","GND")]),
("C10","Input bulk polymer","68uF 25V, <=5mm tall","D case",A,[(1,"","PPHV"),(2,"","GND")]),
("C11-C14","Output bulk (battery side)","4x 22uF 25V X7R, plus C15","1210",A,[(1,"","BAT_SNS_P"),(2,"","GND")]),
("C15","Battery bulk polymer","68uF 25V, <=5mm tall","D case",A,[(1,"","VBAT_SYS"),(2,"","GND")]),
("R4","FB top","243k 0.1%","0402",A,[(1,"","VBAT_SYS"),(2,"","CHG_FB")]),
("R5","FB bottom","24.9k 0.1%","0402",A,[(1,"","CHG_FB"),(2,"","CHG_FBG")]),
("R6","ICHG set","16.9k 1% (2.96A)","0402",C,[(1,"","CHG_ICHG"),(2,"","GND")]),
("R7","ILIM set","4.02k 1% (about 5A with 5mOhm R1)","0402",A,[(1,"","CHG_ILIM"),(2,"","GND")]),
("R8","FSW set","66.5k 1% (400kHz)","0402",C,[(1,"","CHG_FSW"),(2,"","GND")]),
("R9","TS upper","5.23k 1%","0402",C,[(1,"","REGN"),(2,"","CHG_TS")]),
("R10","TS lower","30.1k 1%","0402",C,[(1,"","CHG_TS"),(2,"","GND")]),
("RT1","NTC on cell","10k 103AT, on leads","wired",C,[(1,"","CHG_TS"),(2,"","GND")]),
("R11","ACUV/ACOV divider top","value from datasheet section 6.3","0402",T,[(1,"","CHG_VAC"),(2,"","CHG_ACOV")]),
("R12","ACUV/ACOV divider mid","value from datasheet section 6.3","0402",T,[(1,"","CHG_ACOV"),(2,"","CHG_ACUV")]),
("R13","ACUV/ACOV divider bottom","value from datasheet section 6.3","0402",T,[(1,"","CHG_ACUV"),(2,"","GND")]),
("R14","CE pull-down","10k","0402",A,[(1,"","CHG_CE_N"),(2,"","GND")]),
("R15","INT pull-up","10k","0402",C,[(1,"","CHG_INT"),(2,"","PD_3V3")]),
("R16","I2Cc SDA pull-up","3.3k","0402",C,[(1,"","CHG_SDA"),(2,"","PD_3V3")]),
("R17","I2Cc SCL pull-up","3.3k","0402",C,[(1,"","CHG_SCL"),(2,"","PD_3V3")]),
("R18","I2Ct SDA pull-up","4.7k","0402",C,[(1,"","HOST_SDA"),(2,"","3V3")]),
("R19","I2Ct SCL pull-up","4.7k","0402",C,[(1,"","HOST_SCL"),(2,"","3V3")]),
("R20","Host IRQ pull-up","10k","0402",A,[(1,"","HOST_IRQ"),(2,"","3V3")]),
("R21-R23","STAT1/STAT2/PG pull-ups","3x 100k","0402",A,[(1,"","CHG_STAT1 / CHG_STAT2 / CHG_PG"),(2,"","3V3")]),
("C16","LDO_3V3 cap","10uF 6.3V","0603",C,[(1,"","PD_3V3"),(2,"","GND")]),
("C17","LDO_1V5 cap","10uF 6.3V","0603",C,[(1,"","PD_1V5"),(2,"","GND")]),
("C18","VIN_3V3 cap","10uF 6.3V","0603",C,[(1,"","3V3"),(2,"","GND")]),
("C19","VBUS cap","4.7uF 35V","0805",C,[(1,"","VBUS1"),(2,"","GND")]),
("C20","PP5V cap","22uF 10V","0805",C,[(1,"","5V"),(2,"","GND")]),
("C21","CC1 cap","330pF","0402",C,[(1,"","P1_CC1"),(2,"","GND")]),
("C22","CC2 cap","330pF","0402",C,[(1,"","P1_CC2"),(2,"","GND")]),
("R24,R25","ADCIN1 strap divider","level chosen in TI GUI","0402",T,[(1,"","PD_3V3 / GND"),(2,"","ADCIN1")]),
("R26,R27","ADCIN2 strap divider","level chosen in TI GUI","0402",T,[(1,"","PD_3V3 / GND"),(2,"","ADCIN2")]),
("U3","I2C EEPROM","size and address per TPS25751 datasheet","SOT-23-5 or UDFN",T,[("SDA","","CHG_SDA"),("SCL","","CHG_SCL"),("VCC","","PD_3V3"),("GND","","GND")]),
("D1","VBUS TVS","TVS2200 or equivalent","SON",C,[(1,"","VBUS1"),(2,"","GND")]),
("D2","CC/D+/D- ESD array","4-channel, 24V-tolerant on CC","SOT/DFN",T,[("IO","","P1_CC1, P1_CC2, P1_DP, P1_DN"),("GND","","GND")]),
("J1","Amphenol 12402082E512A","Port 1 USB-C","vertical SMT",A,[("VBUS","A4/A9/B4/B9","VBUS1"),("GND","A1/A12/B1/B12/shell","GND"),("CC1","A5","P1_CC1"),("CC2","B5","P1_CC2"),("D+","A6/B6","P1_DP"),("D-","A7/B7","P1_DN")]),
]
blocks_pending = [("Protector","BQ77915 + 2 FETs + 5mOhm sense + 15A fuse","between cell stack and VBAT_SYS","pinout not yet pulled"),
 ("3.3V rail","TPS709 LDO","VBAT_SYS -> 3V3","pinout not yet pulled"),
 ("5V rail and port 2","TPS62933 buck, J2, 4.7k CC pull-ups","VBAT_SYS -> 5V, 5V -> VBUS2 through a load switch","pinout not yet pulled"),
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

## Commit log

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2026-10-09 Draft 6: datasheet corrections to charger and PD controller wiring
    - Fix ACUV/ACOV divider order (VAC > ACUV > ACOV > GND) and set values
    for a 4.4 V to 24 V input window (1M / 267k / 66.5k)
    - Charge voltage divider now 249k / 25.5k per TI's equation (16.5 V)
    - TPS25751 boot strap: ADCIN1 to LDO_3V3, ADCIN2 to GND (SafeMode),
    strap resistors removed
    - Note I2C addresses on the sheet
    Claude-Session: https://claude.ai/code/session_017ypupkahdxpHbW4uwEu58x
    [BatteryBank.kicad_sch, monolith_netlist.csv]
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2026-10-12 Dev board: KiCad schematic for the Monolith dev board
    New KiCad 10 project in DevBoard/ implementing docs/devboard/circuit-description.md
    (draft 5): cells + BQ40Z50-R2 gauge, sleep-current measurement and 3.3 V rail,
    STM32WB1MMC + NTCs, and one USB-C PD port sheet (TPS25751D + BQ25756 + TPS62933)
    placed twice.
    - Project symbol library generated by tools/make_symbols.py, pin numbers checked
    against the datasheets in datasheets/
    - Datasheet-driven corrections to the spec are listed in DevBoard/README.md
    (gauge VCC/PACK networks, TPS709 output cap, PP5V bulk, BQ25756 VAC/DRV_SUP and
    sense filters, STM32WB RF guard caps)
    - Drawn to schematic best practice: functional blocks with notes, po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
2026-10-12 Dev board: project footprints for holder, USB-C, half-bridge, module, EEPROM, BQ25756
    - tools/make_footprints.py generates MonolithDev.pretty from the datasheets:
    BH-21700-B1BJ001 holder, Shou Han USB-C (with board-edge cutout),
    Infineon PG-TDSON-8-57 half-bridge (land + stencil), STM32WB1MMC LGA77,
    ST UFDFPN8 2x3 with the correct 1.2x1.4 exposed pad, and a 10 A net tie
    - BQ25756 RRV0036A footprint from Antmicro (Apache-2.0), checked against TI
    - Footprints assigned; R430/R530 become net-tie links, off the BOM and CPL
    - Every symbol pin has a pad and vice versa; nets, ERC and overlaps unchanged
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2026-10-12 Dev board design review: free PB0-PB2, document PB4 reset state
    - NTC_EN, EN_5V1, EN_5V2 move from PB0/PB1/PB2 (ST: RF-sensitive, leave
    unconnected) to PA8/PA11/PA12; C305-C307 guard caps removed, no-connects added;
    J303 now brings out PA7, PB8 and the three enables
    - Pin map checked against DS13258 table 15 (ADC, wake-up, I2C1, USART1, SWD)
    - PB4 resets as NJTRST with pull-up, so the TPS62177 boots in normal mode,
    not sleep mode as documented; notes and docs corrected
    - MCU notes: module placement per ST's reference PCB
2026-10-12 Dev board: board setup (175x115, 4L 0.8 mm), netlist loaded, PDFN fix
    - Board: 175 x 115 mm (the four holders need ~96 x 110), 4 layers 0.8 mm,
    2 oz outer / 1 oz inner, ENIG stack-up; six M3 board-only holes; outline
    broken for the two USB-C notches, J401/J501 placed and locked on the right edge
    - JLC rules, via/track presets, net classes (HighCurrent, Power, GND,
    GateDrive) and custom rules in MonolithDev.kicad_dru (tools/setup_board.py)
    - Netlist loaded with tools/netlist_to_board.py (the MCP sync merged the two
    ports' nets); kicad-cli parity check reports 0 issues
    - Q101/Q102: AGM404AP1 is a 3.3x3.3 PDFN, not TDSON-8 (5x6); new footprint
    - USB-C signal pads moved 0.2 mm in from th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
2026-10-12 Dev board: first-pass placement (196x115), DRC clean before routing
    - tools/place_parts.py: mechanical (outline, holes, USB-C), hand placement of
    holders, gauge core and VC filter ladder, sleep-current section, MCU and
    both charger power trains; auto placement of the small parts next to the
    pins they serve; silkscreen labels (P1/P2 test points, USB 1/2)
    - Board widened to 196 mm: holder courtyards collided with the corner holes
    - TPS25751 footprint copy with the PPHV/VBUS pad gap opened to 0.15 mm (2 oz)
    - Rules: HighCurrent/Power pad clearance 0.15 mm; 0.25 mm only between
    high-current copper and small-signal copper
    - DRC: 0 placement/clearance/silk issues, 0 parity issues; unrouted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
2026-10-13 Dev board rev A4: design-review fixes, polymer bulk, charge inhibit
    Schematic design review (three reviewers, cross-challenged) in
    docs/devboard/schematic-review-2026-10-12.md, and its fixes:
    - U203 TPS70950 EN no longer tied to PACK_P (would destroy it)
    - ICHG 17.8k: 2.8 A per port (was 9.8 A, above the cells' 5.6 A)
    - U101 footprint from TI RSM0032A (1.4 mm thermal pad, was 2.8 mm)
    - D+/D- ESD now 5 V PESD5V0S2BT (TPS25751 GPIO4/5 are rated 6 V)
    - R101-R104 1206, F101 and J101 DNP, DNP gate parts on Q102
    - BTP_INT buffered by a 2N7002; SMBus pull-ups on a removable 0R
    - Wake button, bench PACK_P header, reset, BOOT0/3V3_SLEEP pads,
    J303 series resistors, IRQ pull-ups, vertical SMAs, BOM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
2026-10-13 Dev board: F101 15 A (1206FA-15A) for 100 W output
    The 8 A fuse allowed about 6 A continuous after derating, 60-70 W out,
    short of the 100 W goal (~10 A from the pack at the 12 V low end).
    prosemi 1206FA-15A (C2838894): same 1206 footprint and 300 A at 24 Vdc
    interrupt rating. Review doc: gauge OLD ~16-20 A, OCD1 ~10-11 A (2-3 A
    in holder mode), output power sharing at 100 W total.
2026-10-13 Dev board: bootstrap diodes, one NTC per cell, 1 % resistors
    - BQ25756 bootstrap Schottkys DRV_SUP -> BTST1/BTST2 on both ports
    (TI BQ25756 schematic checklist D2/D3, required; LRB521S-40T1G,
    SOD-523), placed in line with the BTST caps. Also added to the
    production BOM/netlist.
    - Gauge TS2-TS4 no longer tied to VSS: J105-J107 take a wired 10k NTC
    per cell; all four NTC headers sit beside their cell's tap test point.
    - Precision resistors rounded to stocked UNI-ROYAL 1 % parts (ICHG
    9.1k, ILIM 3.6k, TS 1.8k/5.6k, FSW/ACUV-ACOV, NTC dividers); only the
    charge-voltage and PP5V feedback dividers stay 0.1 %.
2026-10-13 Dev board rev A5: FET ESD caps, review 2, fail-safe CHG_INH, MCU I/O plan
    - Gauge: C110/C111 (2 x 0.1 uF in series) across the protection FET pair,
    TI BQ40Z50-R2 fig. 9-2 C1/C2; C107/C108 across PACK+/PACK- unchanged.
    - Second 3-reviewer schematic review with a challenge round
    (docs/devboard/schematic-review-2-2026-10-12.md, raw files in review2/):
    0 critical, 1 major (gauge precharge config), hardware proposals listed.
    - CHG_INH now fails safe: R417/R517 47k pull-up on CE to 3V3; the MCU
    drives PB8 low to allow charging. MCU IWDG in hardware mode.
    - Decisions: ICHG stays 9.1k; F101 stays 15 A with a gauge cut-off of
    2.8 V/cell or higher under load.
    - docs/devboard/mcu-io-power-sta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
2026-10-13 Dev board rev A5: BAT fed before F101, review 2 hardware fixes, JLC passives
    - Gauge BAT feed follows TI fig. 9-12: D101 from the cell top (CELL_P_RAW)
    before F101, so the gauge stays powered if the fuse opens or is unfitted.
    - C421/C521 100 uF 35 V polymer (same 6.3 mm footprint): about 99 uF worst
    case vs the BQ25756 80 uF minimum after derating.
    - Bootstrap diodes LRB520S-40T1G, Q103 BSS138, DNP C109 4.7 nF (fit D103
    with it), PPHV 0.1 uF and VBUS 10 nF per port, R306 330R, C201 DNP flag.
    - Test points: GND loops by each port's SW probes and in the pack probe
    field, CELL_P_RAW, CE_N, LDO_3V3, LDO_IN, 5V_AMP.
    - JLC part numbers on every resistor and capacitor.
    - Placement for the n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
2026-10-13 Dev board: F101 JLC-placed again; check cells before waking the gauge
    Hand-fitting F101 meant soldering beside an installed 16.8 V stack with no
    fuse, and since the BAT feed moved before F101 it no longer isolated the
    gauge either. The loads sit behind Q101/Q102, which stay off on a fresh
    gauge (FET_EN off), so the cell check moves to before the gauge is woken:
    insert cells, check TP102-TP105 and TP108, then wake and configure.
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2026-10-13 Dev board: open-item pass, J104 diode, antenna keep-out, bring-up checklist
    - D104 SS34 in series with the J104 bench input (reversed lead, back-feed).
    - ANT_KEEPOUT rule area (no tracks/vias/pours, all copper layers) around
    the STM32WB1MMC antenna end, created by place_parts.py.
    - D401 drawn unidirectional; header part numbers (PZ254V-11 family);
    shunt, J301 keying, B-constant, insulated-NTC, sheet-text and R201 notes.
    - docs/devboard/bringup-config-checklist.md: every configuration item from
    both reviews in bring-up order, with review 2's precharge correction;
    review 1's 0 mV precharge line marked superseded.
2026-10-13 Dev board: accept holder contact resistance; record C421 ESR/ripple check
    - Review 1 #4 marked accepted for rev 1 (BH-21700-B1BJ001, 100 mOhm max per
    holder); measure each holder at bring-up, holder mode about 2 A, heavy
    tests on the welded pack via J101.
    - C421/C521 (HV1V107M0607PZ): datasheet ESR 48 mOhm, 1.5 A rms. Worst-case
    bank ripple about 5 A rms in reverse mode; the MLCCs take about 80 %, so
    the polymer sees about 1 A rms.
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2026-10-13 Dev board: 3D models for every physical part; holder, cell, module, renders
    - Cell holders: LCSC EasyEDA model corrected against MYOUNG's drawing
    (side walls clipped/filled to the drawn profile, logo removed, + tab
    added); hidden-line overlays in 3dmodels/verification match both views.
    - EVE INR21700/58E cell as a second model on the holder footprint; axis
    height 13.18 is PROVISIONAL (not in MYOUNG's drawing) - measure.
    - STM32WB1MMC: LCSC EasyEDA model checked against ST fig. 11 / table 3
    (6.5 x 10 x 1.372, pad pattern and pin A1 match the footprint).
    - M24512 UFDFPN8 and the S2761 test loop from their package drawings.
    - 346 of 362 footprints modelled (rest: holes, bare pads, net t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
2026-10-13 Dev board: silkscreen purpose/pinout labels; sleep-current SMAs to test loops
    - Silkscreen: WAKE / RESET / AMP EN / MEAS PWR / SWD part labels and pin
    labels on J101, J102-J107, J103, J104, J303, J402/J502, J301 pin 1
    (place_parts.py PIN_LABELS / PART_LABELS; README item 30).
    - J201/J202 vertical SMAs removed: OUT_LO/OUT_HI probed on TP201/TP202, each
    with a GND loop (TP208/TP209) 4.5 mm away, in a row on the bottom edge.
    R204/R205 49.9R kept (README item 31; docs updated).
    - Renders, 2D exports and schematic PDF regenerated.
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2026-10-13 Dev board: start routing - planes, port power stages, gate drive, USB-C path, 5 V bucks
    - Kelvin net class (0.2 mm / 0.15 mm) for the sense nets.
    - tools/route_power.py (re-runnable, uuid sidecar): per port SW1/SW2 pours,
    input/output bank pours on F.Cu+B.Cu with GND islands stitched to In1,
    VBAT_SYS, gate drive on In2/B.Cu with F.Cu bootstrap loops, BQ25756 EP vias,
    VBUS and PPHV power path with RAC Kelvin taps, TPS62933 5 V buck and the
    PP5V feed to the TPS25751. In1 solid GND, In2 GND fill, M3 hole keep-outs.
    - Placement: RBAT turned 180, SRP/SRN resistors beside it, gate-drive support
    parts regrouped ("fix" entries), C407/C507 0805 -> 0603 (CL10A106MA8NRNC,
    C96446) moved abov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
2026-10-13 Dev board: pack path routed (cell links, CELL_N, CELL_P_RAW, CELL_P, FET_MID, PACK_P bus)
    - Cell links as diagonal F.Cu+B.Cu bands under the holders.
    - RS101 turned (CELL_N pad to the cells, GND pad into a via field).
    - CELL_N column to J101, CELL_P_RAW strip to F101/J101, CELL_P up to Q101,
    FET_MID through drain-pad via grids on B.Cu, PACK_P B.Cu bus to R430/R530,
    R431/R531 and D104.
    - Fixed Q101/Q102 placement entry. DRC 0 violations. README item 32.
2026-10-13 Dev board: GND fanout, Kelvin taps, own A* signal router (first pass)
    - tools/fanout_gnd.py: a via beside every SMD GND pad not already on GND
    copper (144), clear of all other nets, edge rule and antenna keep-out.
    - Hand-routed Kelvin taps: RBAT onto its pads, RS101 pair on In2 to R107/R108;
    U401/U501 GND pins 31/36/37 onto the exposed pad.
    - tools/autoroute.py: Freerouting attempt, kept for reference (rejected:
    plateaued at a third unrouted, broke DRC, ran signals across power stages).
    - tools/route_signals.py: A* maze router on a 0.1 mm grid (power pours and
    GND islands are obstacles, In1 untouched, F.Cu preferred). First full pass
    routed 224 of 392 missing connections; 218 pads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
2026-10-14 Dev board: hand-routed sense pairs, MCU fanout, USB-C front-end rework
    - SRP/SRN, ACP/ACN, gauge SRP/SRN, MEAS+/- and FB/FBG routed by hand
    (In2 pairs under the GND plane, lane order planned so no crossings);
    R303 turned so the RF links don't cross
    - STM32WB1MMC: passive columns moved back, one via per side signal pin
    - USB-C: D401/D403/D402/C401/C402 placed from the connector, TVS moved
    off the signal rows, DP/DN join with one In2 hop, U401 VBUS-sense on
    B.Cu, PP5V run moved up, CC/DP/DN In2 lanes to the front end
    - fanout_gnd strips old items as text (shared tools/pcb_text.py);
    router: track/via island ends, pad snapping, stub cleanup, thermal
    room, hole buckets, octile + weigh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
2026-10-14 Dev board: USB-C liquid detection, schematic review 3 fixes, new datasheets
    Liquid detection (TPS25751 datasheet 9.2.2.2, both ports): TPD2S300 U405/U505
    on SBU1/SBU2 into GPIO4/5, switched 100k pull-up / 1M pull-down (Q403-Q406)
    on GPIO6/7. R440/R540 short D+/D- (passive BC1.2 DCP); D403/D503 removed.
    Schematic review 3 (docs/devboard/schematic-review-3-2026-10-14.md):
    - H1: TPD2S300 FLT -> GPIO3 fault input (SBU_FLT, R441 pull-up), as on
    TI's TPS25751EVM, so a VBUS-SBU short turns VBUS off.
    - H2: R442/R443 hold the liquid-detect FETs off while GPIO6/7 are Hi-Z.
    - H3: BQ25756 tuning parts from the EVM: 0R in gate and BTST lines
    (R444-R449), DNP RC snubbers on SW1/SW2 (R450/C454, R451/C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
2026-10-14 Dev board: cost-down pass (about $113 -> $80 per board at 5 boards)
    Swaps from docs/devboard/cost-down-2026-10-14.md, datasheet-checked:
    - L401/L501 XAL7030 -> SMMS1040-2R2M (Isat 18 A, Irms 12 A, 9 mOhm)
    - L402/L502 SRP5030T -> APS0530M3R3H (new footprint L_Coilank_APS0530)
    - L201 SRN4018TA -> FNR4030S100MT
    - U203 TPS70950 -> HT7550-1, C204/C205 10 uF per Holtek's basic circuit
    - C431/C434/C435 47 uF 1210 -> 22 uF 1206 (bank ~114 uF effective)
    - JLC basic/preferred equivalents: D103, D401, R410/R412, C105/C206,
    C406, Q103 -> AO3400A
    - D301 (out of stock) -> red KT-0603R
    - R431/R531 -> bridged solder jumper
    - 34 test loops -> bare pads; pin headers hand-soldered
    - U301 bought from ST and c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
2026-10-14 Dev board: production column in the costed BOM
    bom_cost.csv gains in_production (yes / no / maybe / partly),
    production_qty_per_board and production_note. Dev-only: holders, test
    points, debug/bench/NTC headers, the sleep-current measurement section and
    its links, SWD/reset (production uses pads). Maybe: wake button, BTP_INT
    shifter, board NTCs, status LED, 0R gate/BTST tuning. Production-intent
    parts come to about $52 per board at dev-board (5-board) prices.
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2026-10-14 Dev board: reset the layout to parts + outline, sync board to schematic
    tools/reset_board.py strips every track (659), via (685), zone (79, incl.
    the antenna keep-out), board silkscreen text (50) and group from the
    board, deletes the 11 parts no longer in the schematic (F101, D403/D503,
    R405-R408, R505-R508), reloads the 61 parts whose footprint changed at
    their old positions, and stages the 75 new parts below the outline.
    netlist_to_board.py then set nets and fields: 0 schematic parity issues.
    Schematic: field placement re-run on gauge and port sheets (0 text
    overlaps, netlist unchanged); SBU_FLT stub shortened. place_parts.py
    points at F102. README layout status and rev2 notes updated, in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
2026-10-15 Dev board: 6-layer 1.6 mm board, TPD4S201 port protector, 1.6 mm USB-C
    - Stack-up: 6 layers, 1.6 mm, 2 oz outer / 0.5 oz inner (In1/In4 GND),
    0.3 mm drill / 0.45 mm via minimum so JLC's small-via surcharge is gone.
    Via-in-pad (POFV) is free on 6+ layers.
    - U405/U505: TPD2S300 (0.4 mm DSBGA) -> TPD4S201TRGRRQ1 (VQFN-20 RGR),
    CC + SBU protection with FLT -> GPIO3. D402/D502 and C453/C553 removed.
    - J401/J501: Shou Han TYPE-C 16PCB1.6 IP68 (C55629729), footprint and
    STEP model generated for the 1.6 mm board.
    - TPS25751 REF0038A thermal vias 0.2 -> 0.3 mm.
    - setup_board.py keeps unmanaged net classes (Kelvin); reset_board.py
    reloads swapped footprints in place.
    - ERC 0 errors, DRC sche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
2026-10-15 README: current status for the repo and the dev board
    Root README now describes the dev board (rev A6, placed, not routed),
    the docs/datasheets folders and the open items; the dev board README
    gets a current header, Status section (ERC, DRC, BOM cost), the new
    tools, the current floorplan, the antenna keep-out note after the
    reset, and footprint table rows for the FETs, TPD4S201 and APS0530.
2026-10-15 Dev board schematic: tidy pass
    - Title blocks on every sheet: rev A6, 2026-10-14, status line updated
    (was "Not reviewed, laid out, built or tested"); tidy_fields.py
    writes the same.
    - Port sheet: the TPD4S201 block is titled with liquid detection
    ("CC/SBU PROTECTION (TPD4S201) + LIQUID DETECTION") and moved clear of
    the heading it collided with; I2Cc heading moved next to the EEPROM;
    PP5V heading clear of U405's GND.
    - MCU sheet: test-point row out of the title block, with a heading;
    long NOTES lines wrapped inside the page border.
    - Gauge sheet: cell-stack heading clear of its note; TP106 joins the
    test-point row.
    - Top sheet: sheet index updated (BQ294700, TPD4S201, TH1-TH5)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
2026-10-15 Dev board rev A7: CC2340R5MODA MCU, TMP1075 sensors, shared IRQ_N
    - U301 STM32WB1MMC -> TI CC2340R5MODA (cost-down; BLE only, on-chip OTA).
    New symbol and footprint (MHA0024A, with the fig. 9-2 antenna keep-out),
    RF match C313/R321/C314/C315, RSTN pull-up R302, wired per SWRS349A fig. 9-1.
    - Only 10 usable GPIOs, so the five board NTCs become TMP1075 I2C sensors:
    U302-U304 fitted (port 1 stage, port 2 stage, connectors), U305/U306 DNP.
    FET over-temperature moves to the gauge internal sensor.
    - TPS25751 IRQs, gauge BTP and TMP1075 ALERTs share one open-drain IRQ_N
    (R314 pull-up; R315, R114 DNP).
    - R313 fitted at 470k: CC2340 pins float in reset, so it keeps the 3V3 rail
    out of sle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
2026-10-15 Dev board rev A7 layout: CC2340R5MODA and TMP1075 placed
    - Board updated to the rev A7 schematic: U301 CC2340R5MODA at the top edge
    with its RF match, TMP1075 U302-U306 on the copper they measure.
    - TMP1075 footprint with 0.3 mm thermal vias (JLC minimum) in place of
    KiCad's 0.2 mm ThermalVias variant.
    - DRC 0 errors, schematic parity 0, ERC at the usual 8 warnings.
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2026-10-15 Schematic review 4: rev A7 team review (4 reviewers, challenge round)
    Report: docs/devboard/schematic-review-4-2026-10-14.md. 0 critical,
    2 major, 20 minor, 12 config, 9 doc. Nothing is wired wrongly.
    - B-1 (MAJOR): the always-on high-side charger FETs (Q402/Q502, Q401/Q501)
    run on a bootstrap gate that sags to 2.7-3.9 V, where the PGQ04N070 is
    not specified. Replacement spec and candidates in the report; interim
    IBAT_REV = 5 A.
    - A-2 (MAJOR): the "EV2400 with 3V3 dead" checklist step overdrives the
    unpowered CC2340's I2C pins. Procedure fix: J104 powered, MCU in reset.
    - The challenge round downgraded A-1 (DIO21 bootloader trigger) to a
    blocking CONFIG item plus R313 -> 220k, and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
2026-10-15 Review 4 follow-up: B-1 re-graded, ship mode for storage, gate-drive test
    - B-1 MAJOR -> MINOR. TI E2E (applications engineering) says the BQ25756
    holds a 100 %-duty high-side gate up with an internal charge pump, which
    the datasheet doesn't document. TI's EVM uses SiR680LDP, the same 2.5 V
    max threshold as the PGQ04N070. Keep the PGQ04N070; verify at bring-up.
    Review totals now 1 major (A-2), 21 minor.
    - S-1 (new): the gauge's default Shutdown Voltage of 1750 mV/cell lets a
    stored pack drain into deep over-discharge after CUV. Decided: 2700 mV,
    and ship mode (MAC 0x0010) on an app command, after two weeks with no
    cable or button, or at low SOC. Wake on a USB charger or SW101.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
2026-10-15 Dev board rev A8: review 4 pre-routing hardware fixes
    Applied by tools/review4_fixes.py (one-shot from the rev A7 sheets);
    part numbers checked against JLC's parts API.
    - R313 470k -> 220k (3V3_SLEEP margin), R314 100k -> 47k (IRQ_N),
    R304/R305 4.7k -> 3.3k (I2C rise time)
    - R322/R323 1k in series with J302 TX/RX; R324 1k at J303 pin 2
    - C314 placeholder 1p C0G (DNP); C401/C402 330p -> 220p (CC capacitance)
    - R450/R451 snubber resistors -> 1206 0.66 W (a 2010/0612 doesn't fit)
    - D401/D501 SMAJ22A -> TVS2200DRVR flat clamp (stock KiCad symbol and
    footprint; datasheet added)
    - TP415-TP421 (+5xx) 1 mm probe pads on CC, SBU and liquid-detect nets
    Board synced and placed (place_blocks.py): 42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
2026-10-15 Dev board rev A8 part 2: review 4 docs, BOM, A-2 procedure, J104 clamp
    Schematic edits by tools/review4_docs.py (helpers split out of
    review4_fixes.py into tools/sch_edit.py; review4_fixes output unchanged).
    - A-2: EV2400 work only with 3V3 up (J104) and U301 in reset; checklist,
    R312/R301 Notes and MCU sheet note 10 rewritten.
    - D-5: D105 SMAJ18A clamp on the J104 side of D104; board placed
    (D104 moved one body width left).
    - Stale Notes, sheet notes, heading and address text fixed; sheet 4
    renamed "MCU and Sensors"; revision log A7/A8; title blocks A8.
    - MPNs filled on the parts that had only LCSC numbers; Sourcing on U301
    and J301; J301 out of the position file.
    - bringup-config-c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
2026-10-15 Dev board: hybrid battery-side bulk, ship mode at 5 % SOC, CC2340 in stock
    - C432/C532 (battery-side bulk, the only bulk cap biased in idle) ->
    Panasonic EEH-ZA1E101XP hybrid polymer (C264047), CP_Elec_6.3x7.7.
    Same 100 uF / 30 mOhm as the JIERR solid polymer, but leakage limit
    0.01CV = 25 uA instead of 0.2CV = 500 uA. +$1.28 per board. README
    item 43; review 4 B-4 closed. Board synced: 0 parity issues, no
    courtyard overlaps.
    - Ship mode also triggers at RSOC <= 5 % (checklist, power states,
    review 4 S-1).
    - CC2340R5MODA is in stock at TI.com (seen logged in, 2026-10-15):
    U301 Sourcing, bom_cost.py, checklist and README notes updated.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
2026-10-16 Dev board: cut JLC extended parts 37 -> 27 for a 2-board build
    tools/bom_fee_cut.py (one-shot); README item 44. At 2 boards the costed
    BOM goes from $124.28 to $108.49 per board.
    - Basic/preferred swaps, no footprint changes: C313 -> C1548, C315/C314
    -> C1550, C401/C402 -> C1530 (X7R), R433/R434 -> 120k/22k 1 %
    (PP5V 5.16 V), C443/C543 -> 100 uF 35 V Honor polymer (same as C421).
    - Hand-fit from LCSC: BT101-BT104, the 13 Harwin test loops, U202, D105
    (dev-only; out of the position file).
    - Board: fields refreshed by netlist_to_board.py; also includes Logan's
    block move made in KiCad. DRC parity 0; ERC unchanged.
2026-10-16 Firmware: LaunchPad plan and LPF3 bring-up skeleton
    - docs/devboard/launchpad-cc2340-plan.md: what to do with the
    LP-EM-CC2340R53 before the dev board exists (probe rehearsal of the
    J102 -> J301 hookup, then tests T1-T9 for the review 4 CC2340 risks)
    - firmware/: command-line build (gmake, TI Arm Clang, SysConfig) in the
    style of TI's SDK examples, NoRTOS skeleton (banner + reset reason on
    the XDS110 UART, heartbeat LED, IRQ stand-in on BTN-1), CCFG with LF
    RCOSC and the DIO21 bootloader pin trigger off, install instructions
    - Not built yet: no TI tools are installed on this machine
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
